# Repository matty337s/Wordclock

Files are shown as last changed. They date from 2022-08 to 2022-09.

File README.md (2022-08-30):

# Wordclock
PCB hardware design for controller and LED strips for easy manufacture of a wordclock.

Initially based on the [Wordclock by t0mg](https://github.com/t0mg/wordclock), this project is designed to intergrate with the firmware from their project with slight modification. Check it out if you haven't already. 

The PCB panel and BOM contain all of the electronics to complete the clock. No LED strips or wiring required. 114 LEDs display the time to the minute using words for a unique, modern and functional clock.

This is a hobby for me, although it does take a lot of time and effort! If you like the project, please consider buying me a coffee by clicking [donate](https://www.paypal.com/donate/?hosted_button_id=GT76NKYH2WRKS). It is very much appreciated.

Kits and/or assembled and programmed PCBs may be avalible in the future. Let me know if this is something you would be interested in.

**This is a work in progress. Please check back regularly for updates!**

# Where to find files
KiCad files are located in the [Hardware](https://github.com/matty337s/Wordclock/tree/main/Hardware)  folder.

Gerber and assembly files are located in the [Production](https://github.com/matty337s/Wordclock/tree/main/Hardware)  folder. The assembly files are for JLCPCBs assembly service, and all components (excluding phototransistor and pin header) can be provided and assembled by them. I am not affiated with them in any way, and the assembly files can be easily modified for other manufacturers.

CAD files for laser cutting the clockface and internal structure are located in the [CAD](https://github.com/matty337s/Wordclock/tree/main/CAD)  folder. **WIP**

Firmware files for the ESP32 microcontroller are located in the [Firmware](https://github.com/matty337s/Wordclock/tree/main/Firmware)  folder. **WIP**

# Hardware
### Features
* 114 RGB LEDs make up the 11x10 display, showing 110 letters for every time in 5 minute intervals and four minute LEDs for minutes between these intervals.
* PCF8563T RTC (Real Time Clock) with 70mF supercapacitor backup keeps time setting during power loss. The designed 70mF capacitor should hold backup time for ~7 days.
* Photo-transistor for dimming the clock face in low-light. RoHS compliant transistor without cadmium as found in LDRs.
* WiFi connectivity using the ESP32. Allows endless possiblity of color, brightness, time setting, and many more. 
* Three programmable buttons for manual control without WiFi. Can be used as a dumb clock without any WiFi connection by setting the time and AM/PM indicator using the pushbuttons. The buttons are located on the front of the board for cheap and easy assembly, but footprints are provided on the rear if required. Soldering to the rear allows for easy access by pen from the back of the assembled clock.
* Powered by a USB-C receptacle. This port also allows serial data to the ESP32 for easy programming and debugging using a CH340C chip. USB power supply must be rated for about 2.5A.

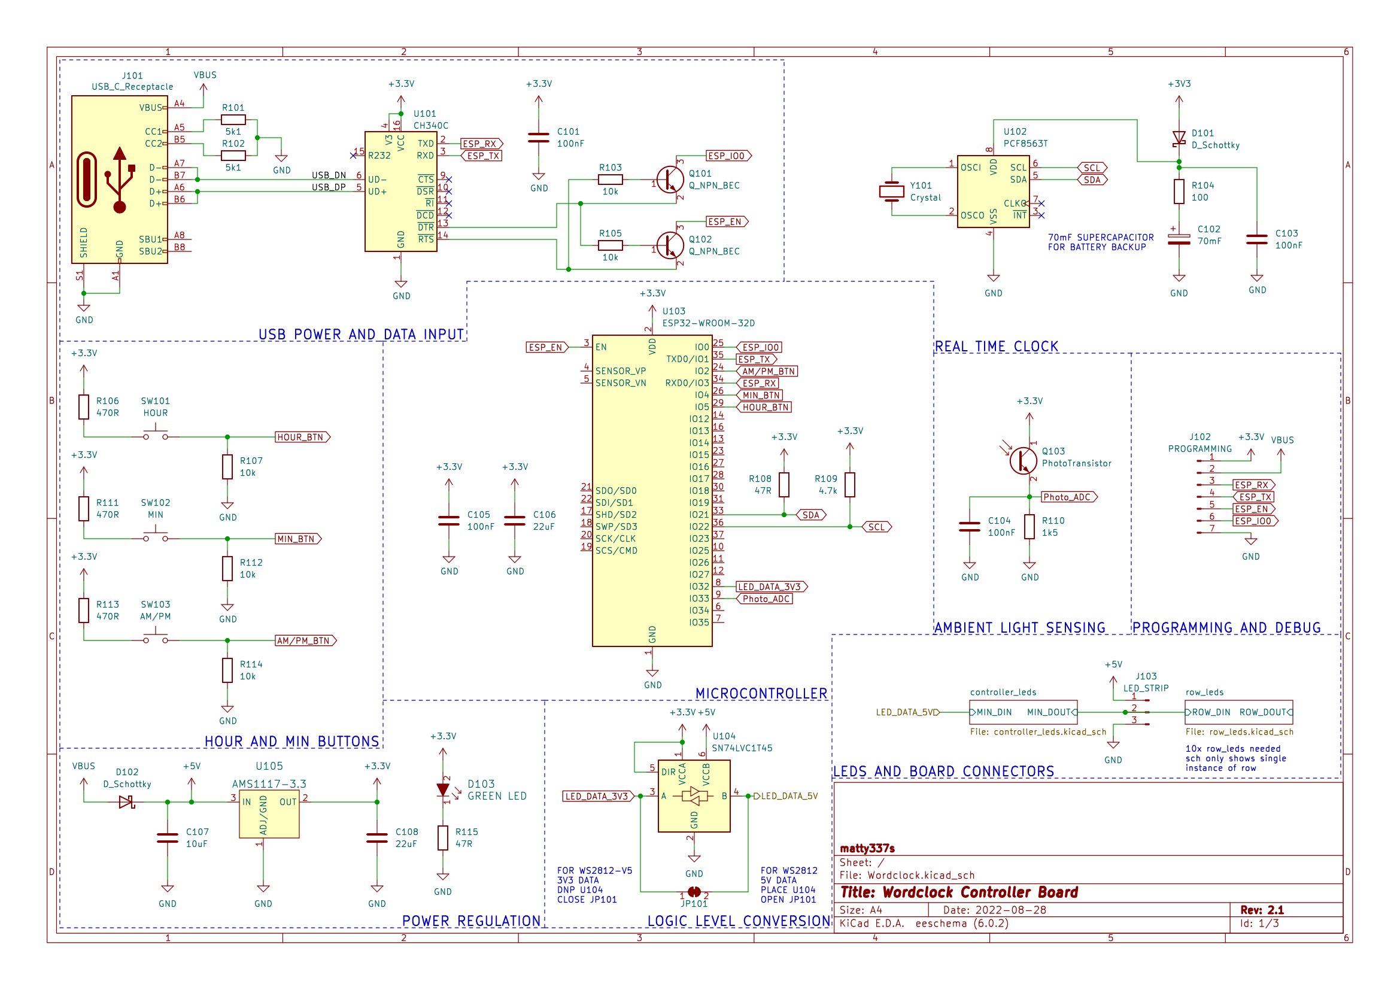
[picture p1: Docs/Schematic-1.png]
Schematic


### PCB
The PCB is panelised with 10 identical boards for the LED strips and one controller board. Boards are assembled by breaking out of the panel and soldering board to board connectors together. This reduces the overal size and cost of the panel. Be sure to select `Different Design = 2` and `Panel by Customer` to avoid unexpected charges.
The LEDs are arranged in 16.6mm intervals. This is the same as 60LEDs per meter standard strips, which can be easily subsituted in if prefered. 
Footprints are included for a 100nF capacitor next to every LED, and a logic level translator chip (U104) to convert the 3.3V ESP32 output to 5V logic for the WS2812B LEDs. If you are using V5 LEDs [WS2812B-V5](http://www.world-semi.com/DownLoadFile/141), you can omit (DNP) all of the 100nF caps relating to the LEDs (C201-204 & C301-311) and U104. When populating these components, cut jumper JP101.

The assembled PCB has a maximum size of approximatly 190mm x 220mm. The panelised PCB, including edge rails, has a size of approximatly 212mm x 150mm. It is designed to fit in a 300mm x 300mm (12in x 12in) picture frame (I used [this](https://www.kmart.co.nz/product/photo-frame-12in-x-12in-black-42613893/) one here) but the outside cut line of the CAD files can be increased (or decreased slightly) to accomodate different size frames.

Panelised PCB

Image created using [TraceSpace](https://tracespace.io)

# CAD
The clockface and internal structure is very similar to the design by [t0mg](https://github.com/t0mg/wordclock), having added a cutout shape for the PCB, minute LEDs
and strain relief for the USB cable. 

It is comprimised of two or three layers of laser cut MDF for the structure and one sheet of laser engraved material for the face.

Layer 3.  The back layer contains the cutout for the PCB and LEDs. Ideally 3mm thick.
Layer 2.  The middle layer/s contain cutout for the USB cable and larger openings for the LEDs to diffuse and light each letter evenly. Ideally 6mm thick, or 2x 3mm. Two sheets of baking paper can be sandwiched between these layers to further enhance the diffusion and even lighting.
Layer 1.  The clockface can be created either using the excelent painted and engraved glass tutorial [here (again from t0mg)](https://github.com/t0mg/wordclock/blob/main/hardware/faceplate/README.md) or more simply and reliably but also more expensive by using a commercial solution called "reverse engravable laminate". 

It is the same concept as the painted glass but using a laminated clear and black plastic. I have had some fantastic results using it. IPI has their version [here](https://www.inoplas.com/laserables-reverse) and Trotec has their version [here](https://www.trotec-materials.com/laser-materials/plastic/trolase-reverse.html). I'm sure there are many others, let me know what you find works well.

I will hopefully get up some assembly guides and images in the coming months.

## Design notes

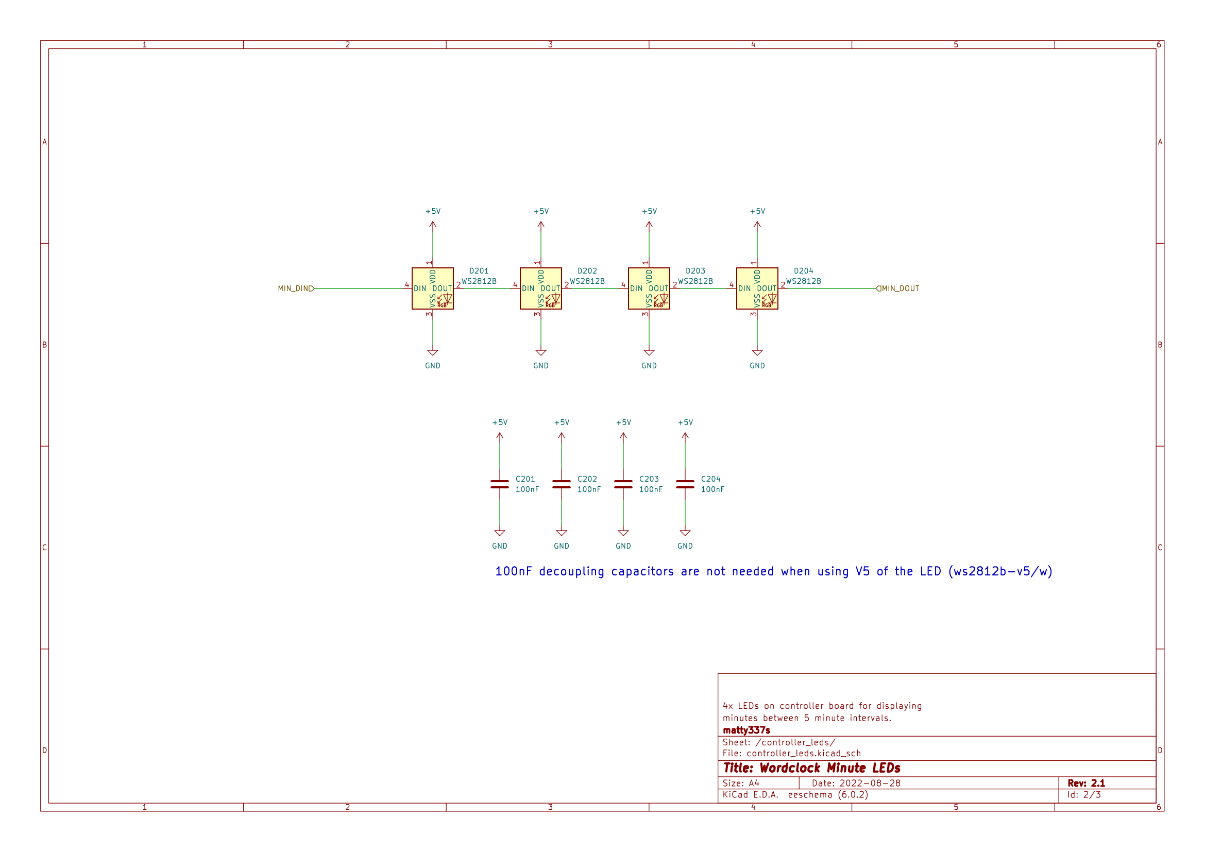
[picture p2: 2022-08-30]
Docs/Schematic-2.png

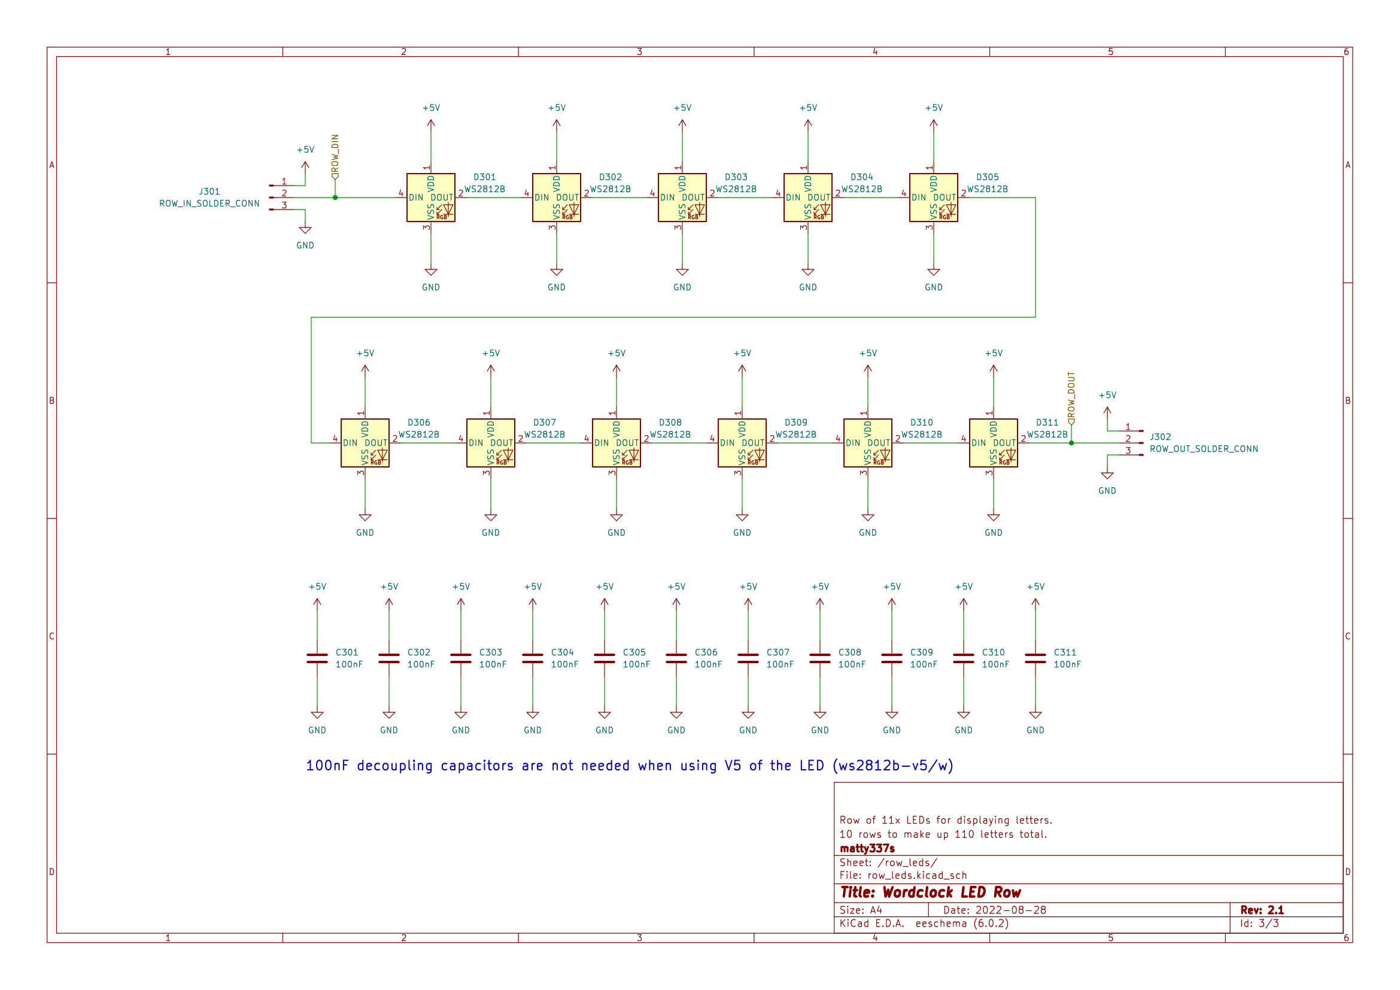
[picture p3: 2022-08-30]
Docs/Schematic-3.png

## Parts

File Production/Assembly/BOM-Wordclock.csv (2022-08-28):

Comment | Designator | Footprint | LCSC
100nF | C101,C103,C104,C105 | C_0603_1608Metric | C14663
D_Schottky | D101,D102 | D_SMA | C14996
10uF | C107 | C_0805_2012Metric | C15850
USB_C_Receptacle_USB2.0 | J101 | USB_C_Receptacle_Palconn_UTC16-G | C167321
100 | R104 | R_0805_2012Metric | C17408
Q_NPN_BEC | Q101,Q102 | SOT-23 | C20526
GREEN LED | D103 | LED_0805_2012Metric | C2297
4.7k | R109 | R_0603_1608Metric | C23162
470R | R106,R111,R113 | R_0603_1608Metric | C23179
47R | R108,R115 | R_0603_1608Metric | C23182
5k1 | R101,R102 | R_0603_1608Metric | C23186
10k | R103,R105,R107,R112,R114 | R_0603_1608Metric | C25804
WS2812B | D201,D202,D203,D204,D301,D302,D303,D304,D305,D306,D307,D308,D309,D310,D311 | LED_WS2812B_PLCC4_5.0x5.0mm_P3.2mm | C2874885
HOUR | SW101,SW102,SW103 | SW_SPST_TL3342 | C318884
70mF | C102 | SM3R3703T01U | C396469
1k5 | R110 | R_0805_2012Metric | C4310
ESP32-WROOM-32D | U103 | ESP32-WROOM-32 | C529577
22uF | C106,C108 | C_1206_3216Metric | C5672
AMS1117-3.3 | U105 | SOT-223-3_TabPin2 | C6186
PCF8563T | U102 | SOIC-8_3.9x4.9mm_P1.27mm | C7440
CH340C | U101 | SOIC-16_3.9x9.9mm_P1.27mm | C84681
Crystal | Y101 | Crystal_SMD_3215-2Pin_3.2x1.5mm | C907543

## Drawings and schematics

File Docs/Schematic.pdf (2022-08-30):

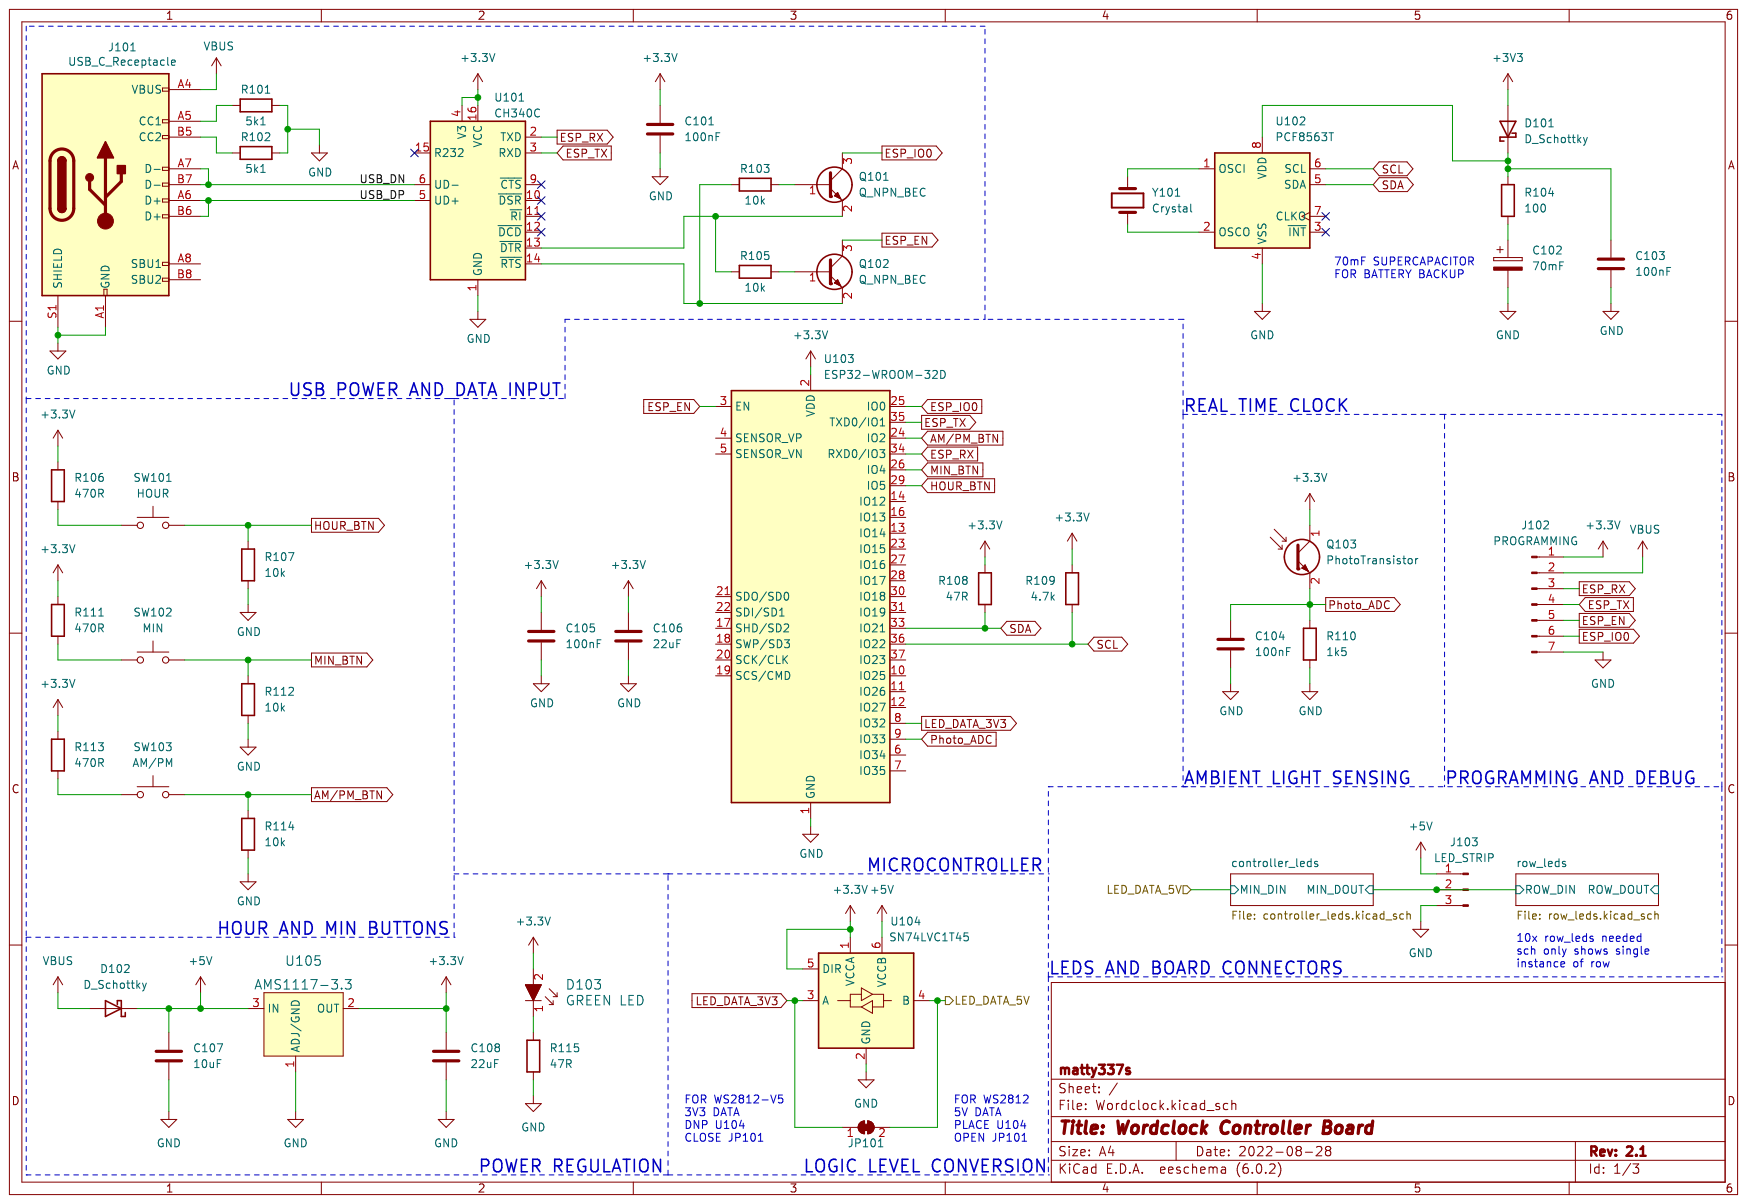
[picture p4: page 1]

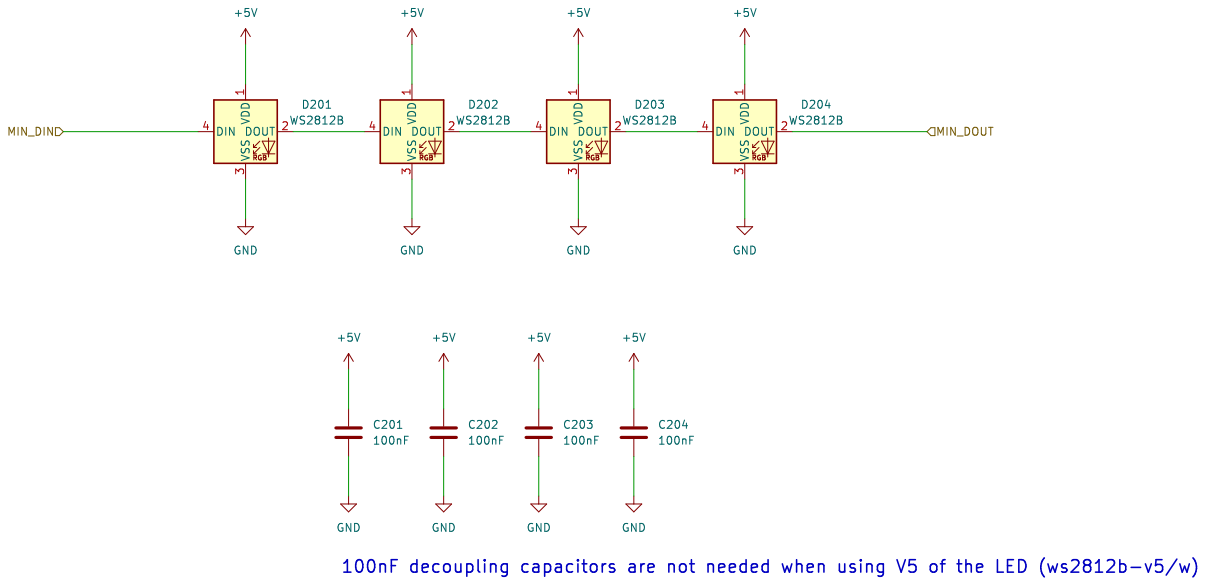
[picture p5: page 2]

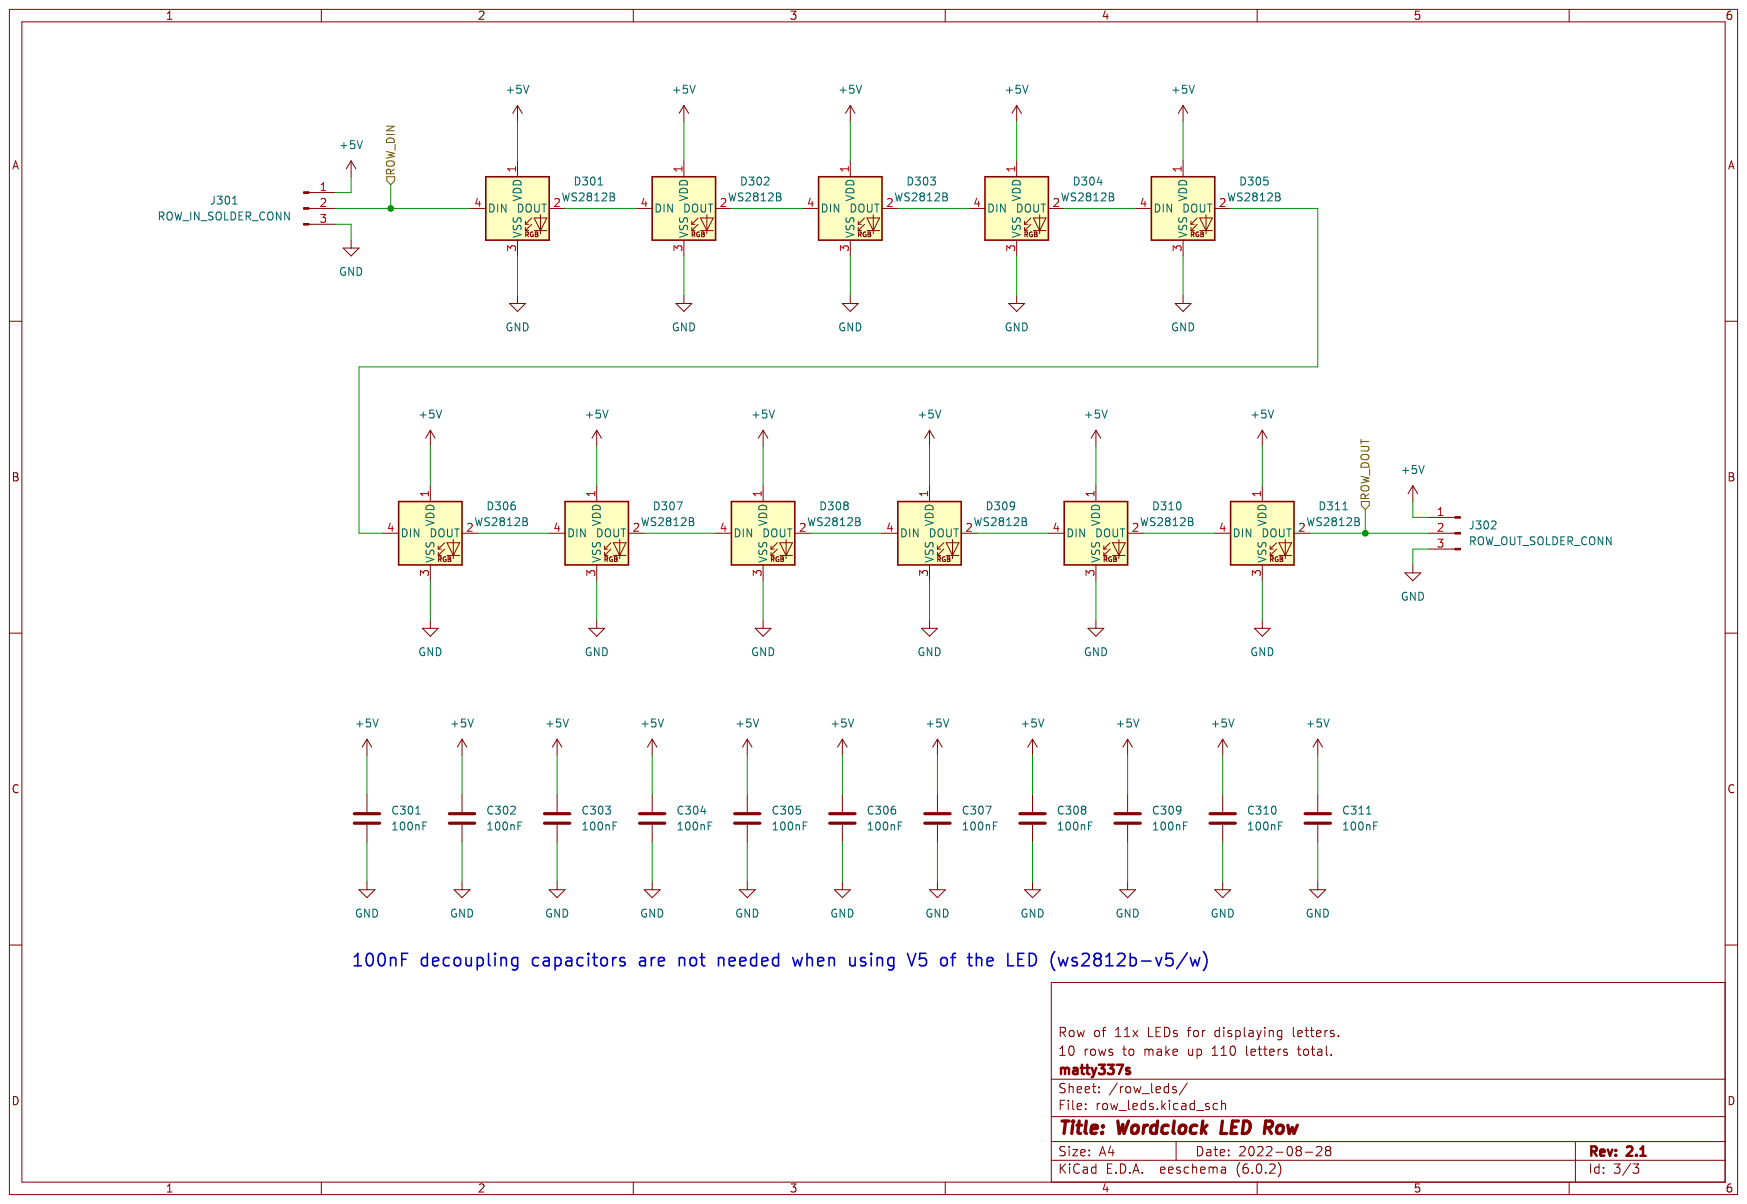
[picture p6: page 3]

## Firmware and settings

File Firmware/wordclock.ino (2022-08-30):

// Define debug to turn on debug logging.
// #define DEBUG 1
#include <Arduino.h>
#include <RTClib.h>

#include "src/logging.h"
#include "src/Display.h"
#include "src/ClockFace.h"
#include "src/Iot.h"

RTC_DS3231 rtc;
EnglishClockFace clockFace(ClockFace::LightSensorPosition::Bottom);
// FrenchClockFace clockFace(ClockFace::LightSensorPosition::Bottom);
Display display(clockFace);
Iot iot(&display, &rtc);

void setup()
{
  setupLogging();

  bool result = rtc.begin();
  DCHECK(result, "RTC didn't start");
  if (rtc.lostPower())
  {
    DCHECK("RTC lost power. Battery was removed ?");
  }

  display.setup();
  iot.setup();
}

void loop()
{
  DateTime now = rtc.now();
  display.updateForTime(now.hour(), now.minute(), now.second());
  display.loop();
  iot.loop();
}

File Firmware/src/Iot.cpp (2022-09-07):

#include "logging.h"
#include "Iot.h"
#include "Timezones.h"

#include <NeoPixelBus.h>
#include <WiFi.h>

// Name of this IoT object.
#define THING_NAME "WordClock"
// Initial WiFi access point password.
#define INITIAL_WIFI_AP_PASSWORD "12345678"
// IoT configuration version. Change this whenever IotWebConf object's
// configuration structure changes.
#define CONFIG_VERSION "1"
// Port used by the IotWebConf HTTP server.
#define WEB_SERVER_PORT 80
// Default timezone index from Timezones.h (New Zealand).
#define DEFAULT_TIMEZONE "423"
// HTTP OK status code.
#define HTTP_OK 200
// NTP server.
#define NTP_SERVER "pool.ntp.org"
// When NTP is enabled, define how often to update the RTC.
#define NTP_POLL_DELAY_SECONDS 86400 // Once a day is plenty enough.

namespace
{

  // An SVG logo for the Word Clock
  const char LOGO_DATA_URI[] PROGMEM = "data:image/svg+xml,%3Csvg xmlns='http://www.w3.org/2000/svg' viewBox='0 0 480 480'%3E%3Cpath d='M0 0h480v480H0z'/%3E%3Cg fill='%23fff'%3E%3Cpath d='M150.692 163.411h-6.563l-11.522-38.242q-.82-2.54-1.836-6.406-1.016-3.867-1.055-4.649-.86 5.157-2.735 11.29L115.81 163.41h-6.563l-15.195-57.109h7.031l9.024 35.273q1.875 7.422 2.734 13.438 1.055-7.148 3.125-13.984l10.234-34.727h7.031l10.742 35.04q1.875 6.054 3.164 13.671.742-5.547 2.813-13.516l8.984-35.195h7.031z' aria-label='W'/%3E%3Cpath d='M268.677 134.718q0 13.711-6.954 21.562-6.914 7.852-19.258 7.852-12.617 0-19.492-7.695-6.835-7.735-6.835-21.797 0-13.945 6.875-21.602 6.875-7.696 19.53-7.696 12.306 0 19.22 7.813t6.914 21.562zm-45.508 0q0 11.602 4.921 17.617 4.961 5.977 14.375 5.977 9.493 0 14.336-5.977t4.844-17.617q0-11.523-4.844-17.46-4.804-5.977-14.258-5.977-9.492 0-14.453 6.015-4.922 5.977-4.922 17.422z' aria-label='O'/%3E%3Cpath d='M154.135 244.514q0 14.14-7.696 21.64-7.656 7.462-22.07 7.462h-15.82v-57.11h17.5q13.32 0 20.703 7.383t7.383 20.625zm-7.032.234q0-11.172-5.625-16.836-5.586-5.664-16.64-5.664h-9.65v45.625h8.087q11.875 0 17.852-5.82 5.976-5.86 5.976-17.305z' aria-label='D'/%3E%3Cpath d='M339.34 139.658v23.75h-6.641v-57.109h15.664q10.508 0 15.508 4.023 5.039 4.024 5.039 12.11 0 11.327-11.484 15.311l15.508 25.664h-7.852l-13.828-23.75zm0-5.703h9.101q7.031 0 10.312-2.773 3.281-2.813 3.281-8.399 0-5.664-3.36-8.164-3.32-2.5-10.702-2.5h-8.633z' aria-label='R'/%3E%3Cpath d='M245.577 219.873q-9.414 0-14.883 6.289-5.43 6.25-5.43 17.148 0 11.211 5.235 17.344 5.273 6.094 15 6.094 5.976 0 13.633-2.149v5.82q-5.938 2.227-14.648 2.227-12.617 0-19.492-7.656-6.836-7.656-6.836-21.758 0-8.828 3.281-15.469 3.32-6.64 9.531-10.234 6.25-3.594 14.688-3.594 8.985 0 15.703 3.282l-2.812 5.703q-6.485-3.047-12.97-3.047z' aria-label='C'/%3E%3Cpath d='M156.44 354.9q0 13.711-6.953 21.562-6.914 7.852-19.258 7.852-12.617 0-19.492-7.696-6.836-7.734-6.836-21.797 0-13.945 6.875-21.602 6.875-7.695 19.531-7.695 12.305 0 19.219 7.813t6.914 21.562zm-45.508 0q0 11.602 4.922 17.617 4.96 5.977 14.375 5.977 9.492 0 14.336-5.977t4.844-17.617q0-11.523-4.844-17.461-4.805-5.977-14.258-5.977-9.492 0-14.453 6.016-4.922 5.977-4.922 17.422z' aria-label='O'/%3E%3Cpath d='M336.73 273.613v-57.109h6.641v51.094h25.195v6.016z' aria-label='L'/%3E%3Cpath d='M373.956 383.337h-7.813l-20.82-27.695-5.976 5.312v22.383h-6.64v-57.109h6.64v28.32l25.898-28.32h7.852l-22.97 24.805z' aria-label='K'/%3E%3Cpath d='M245.577 329.87q-9.414 0-14.883 6.29-5.43 6.25-5.43 17.147 0 11.211 5.235 17.344 5.273 6.094 15 6.094 5.976 0 13.633-2.148v5.82q-5.938 2.226-14.648 2.226-12.617 0-19.492-7.656-6.836-7.656-6.836-21.758 0-8.828 3.281-15.469 3.32-6.64 9.531-10.234 6.25-3.594 14.688-3.594 8.985 0 15.703 3.282l-2.812 5.703q-6.485-3.047-12.97-3.047z' aria-label='C'/%3E%3C/g%3E%3Cg fill='%23fff'%3E%3Ccircle cx='37.785' cy='37.968' r='7.906'/%3E%3Ccircle cx='439.98' cy='38.047' r='7.906'/%3E%3Ccircle cx='37.785' cy='440.74' r='7.906'/%3E%3Ccircle cx='439.98' cy='440.82' r='7.906'/%3E%3C/g%3E%3C/svg%3E";

  // Custom meta tags to be inserted in the head.
  const char CUSTOM_HTML_META_START[] = "<meta name=\"theme-color\" content=\"#121212\" />\n<link rel=\"icon\" href=\"";
  const char CUSTOM_HTML_META_END[] = "\" type=\"image/svg+xml\" />\n";

  // Custom Javascript block that will be added to the header.
  // See customconfig.js for human-readable version.
  const char CUSTOMHTML_SCRIPT_INNER[] PROGMEM = "document.addEventListener(\"DOMContentLoaded\",function(d){if(d=document.querySelector(\"label[for=iwcThingName]\"))d.innerText=\"Clock name\";if(d=document.querySelector(\"label[for=iwcApPassword]\"))d.innerText=\"AP password (login: admin)\";document.querySelectorAll(\"input[type=password]\").forEach(function(a){var b=document.createElement(\"input\");b.classList.add(\"pwtoggle\");b.type=\"button\";b.value=\"\\ud83d\\udc41\\ufe0f\";a.insertAdjacentElement(\"afterend\",b);b.onclick=function(){\"password\"===a.type?(a.type=\
\"text\",b.value=\"\\ud83d\\udd12\"):(a.type=\"password\",b.value=\"\\ud83d\\udc41\\ufe0f\")}});(d=document.querySelector(\"form\"))&&d.addEventListener(\"submit\",function(){var a=document.querySelector(\"button[type=submit]\");a.innerText=\"Saving...\";a.toggleAttribute(\"disabled\",!0)});document.querySelectorAll(\"input[data-options]\").forEach(function(a){var b=a.value,h=a.getAttribute(\"data-options\").split(\"|\"),f=document.createElement(\"select\");f.name=a.name;f.id=a.id;\"\"===b&&f.appendChild(document.createElement(\"option\"));\
var c=null;h.forEach(function(m,n){var e=m.split(\"/\"),g=m;1<e.length?(g=e.splice(0,1)[0],c&&g==c.label||(c&&f.appendChild(c),c=document.createElement(\"optgroup\"),c.label=g),g=e.join(\" / \")):c&&(f.appendChild(c),c=null);e=document.createElement(\"option\");e.value=n;e.innerText=g;n==b&&e.toggleAttribute(\"selected\");c?c.appendChild(e):f.appendChild(e)});c&&f.appendChild(c);a.id+=\"-d\";a.insertAdjacentElement(\"beforebegin\",f);a.parentElement.removeChild(a)});document.querySelectorAll(\"input[type=range]\").forEach(function(a){var b=\
a.getAttribute(\"data-labels\"),h=b&&b.split(\"|\");b=function(){a.setAttribute(\"data-label\",h?h[parseInt(a.value,10)]||a.value:a.value)};a.oninput=b;b()});var k=document.getElementById(\"ntp_enabled\");if(k){var p=function(a){document.querySelectorAll(\"#date, #time\").forEach(function(b){b.parentElement.style.display=a?\"none\":\"\"});document.getElementById(\"timezone\").parentElement.style.display=a?\"\":\"none\"};k.addEventListener(\"change\",function(a){p(1==k.value)});p(1==k.value)}var l=document.querySelector(\"input[type=color]\");\
l&&(d=function(){document.querySelector(\".logoContainer\").style.backgroundColor=l.value},l.addEventListener(\"input\",d),d())});";
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

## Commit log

2022-08-30 Corrected D103 LED Rotation.
    [POS-Wordclock.csv, Wordclock-B_Mask.gbs, Wordclock-B_Paste.gbp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]
2022-08-30 Add Schematic Images
2022-08-30 Added Schematics
    [controller.kicad_sch]
2022-09-04 Changed NeoTopology Layout
    Changed NeoTopology Layout for non-alternating rows for the PCB hardware rather than flexi-strips.
